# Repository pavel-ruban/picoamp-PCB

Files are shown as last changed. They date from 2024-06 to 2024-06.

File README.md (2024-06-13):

# straddle usb-c connector option (fork changes first 3 images):

pcb|top|bottom|pcb|3d|dev-pcb|dev-3d
--|--|--|--|--|--|--
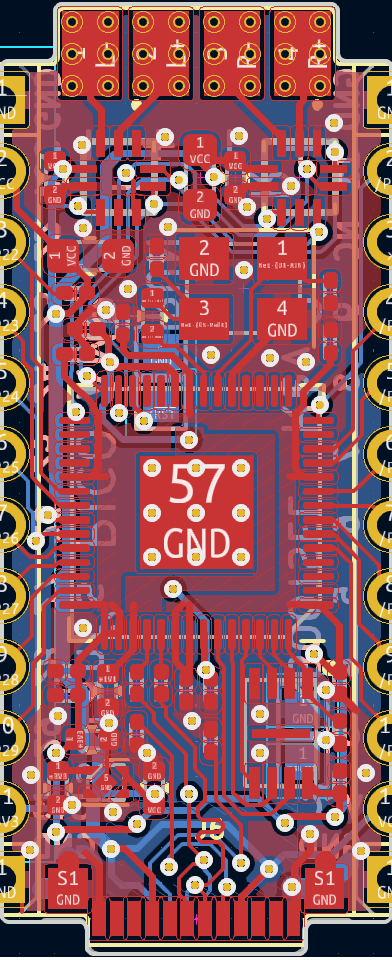
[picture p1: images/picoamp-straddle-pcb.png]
pcb
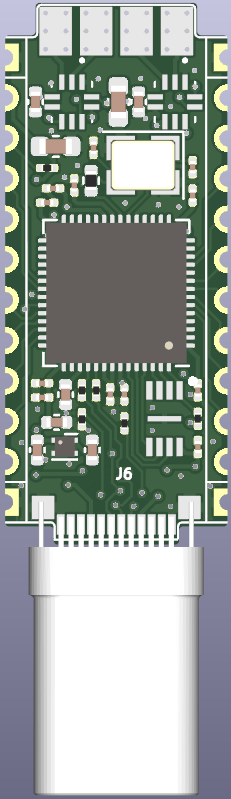
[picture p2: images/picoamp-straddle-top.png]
top
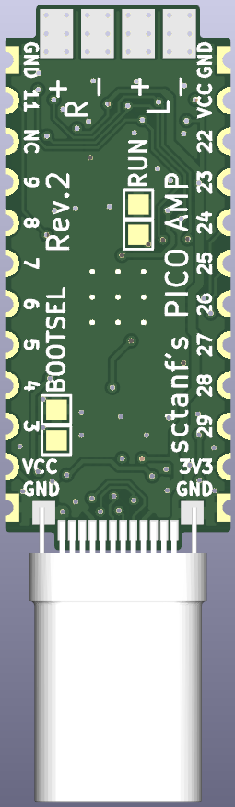
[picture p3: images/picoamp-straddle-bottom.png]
bottom
|||pcb|3d|dev-pcb|dev-3d

* usb c connector https://aliexpress.com/item/1005003274837739.html
* push button soldered on top of the pcb to interact with steamvr dashboard
https://aliexpress.com/item/32622269899.html?sku_id=59394778361

# indexspeakerdacsmol

compact usb-i2s dac using rp2040 and max98360a for powering speakers, like index bmr drivers

* I forgot the silkscreen for usb pins, but they should be clear from below images.
* 0201 components suck to work with.
* intended to use with a usb-c cable, however the CC wire needs 5.1K pull-down to ground which I forgot about

firmware for the device is at https://github.com/sctanf/picoamp

finished board

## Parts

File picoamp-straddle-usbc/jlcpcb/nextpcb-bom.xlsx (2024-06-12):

Manufacturer Part Number* | Qty* | Designator* | FootPrint | JLCPCB Part# | Remarks
CC0402KRX5R6BB104 | 2 | C3,C4 | 0402 | C129131 | ship waste qty with the order pls
0201X104M100CT | 10 | C12,C14,C15,C17,C19,C20,C21,C22,C23,C24 | 0201 | C2443222 | ship waste qty with the order pls
RF03N150F250CT | 2 | C5,C6 | 0201 | C3896518 | ship waste qty with the order pls
CL10A106KP8NNNC | 2 | C1,C2 | 0603 | C19702 | ship waste qty with the order pls
RP2040 | 1 | U1 | LQFN-56(7x7) | C2040 | ship waste qty with the order pls
WR02X102JAL | 1 | R4 | 0201 | C170199 | ship waste qty with the order pls
RM02F5101CT | 3 | R5,R6,R7 | 0201 | C4153144 | ship waste qty with the order pls
RTT0127R0FTH | 10 | R2,R3 | 0201 | C158649 | ship waste qty with the order pls
W25Q16JVUXIQ | 1 | IC3 | USON-8-EP(2x3) | C2843335 | ship waste qty with the order pls
ECS-120-10-33-AGL-TR | 1 | Y1 | SMD3225-4P | C2450497 | ship waste qty with the order pls
ERJ2GEJ102X | 1 | R1 | 0402 | C409846 | ship waste qty with the order pls
MAX98360AEFB+T | 2 | IC1,IC2 | FC2QFN-10(2x2) | C4988888 | ship waste qty with the order pls
MIC5317-3.3YMT-TZ | 1 | U2 | UDFN-4-EP(1x1) | C621348 | ship waste qty with the order pls
GRM155R61C105KA12D | 4 | C7,C8,C16,C18 | 0402 | C77006 | ship waste qty with the order pls
CMS-20103-078SP | 1 | Z3 | speakers | C3311666 | only purchase, no installation, shipped with the order

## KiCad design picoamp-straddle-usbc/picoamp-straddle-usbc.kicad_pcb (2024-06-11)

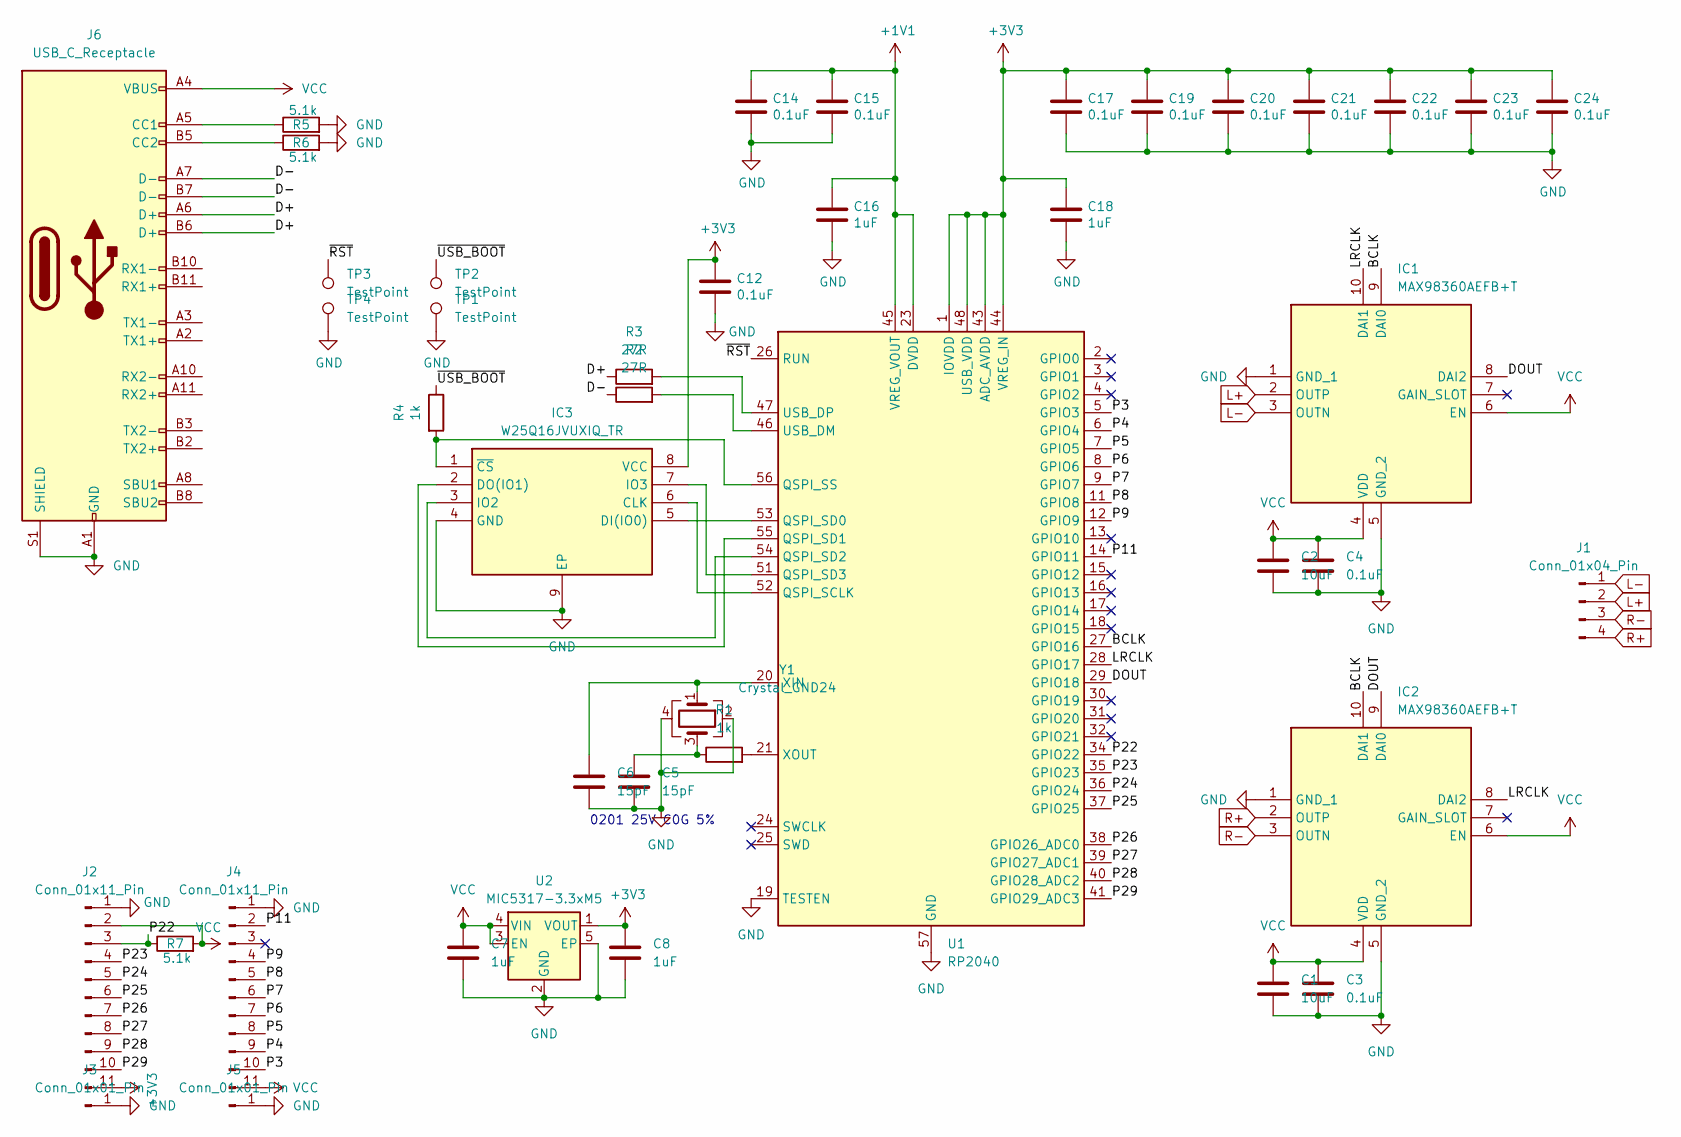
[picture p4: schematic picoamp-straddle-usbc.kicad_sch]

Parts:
C1, C2: 10uF; C_0603_1608Metric; Manufacturer_Part_Number GRM188C81A106MA73D; Mouser Part Number 81-GRM188C81A106MA3D
C3, C4: 0.1uF; C_0402_1005Metric; Manufacturer_Part_Number GRM155R61A104KA01J; Mouser Part Number 81-GRM15R61A104KA01J
C5, C6: 15pF; C_0201_0603Metric; Manufacturer_Part_Number GRM0335C1E150JA01D; Mouser Part Number 81-GRM0335C1E150JA1D
C7, C8, C16, C18: 1uF; C_0402_1005Metric; Manufacturer_Part_Number GRM155C81A105KA12J; Mouser Part Number 81-GRM155C81A105KA2J
C12, C14, C15, C17, C19, C20, C21, C22, C23, C24: 0.1uF; C_0201_0603Metric; Manufacturer_Part_Number GRM033C80J104KE15D; Mouser Part Number 81-GRM33C80J104KE15D
IC1, IC2: MAX98360AEFB+T; MAX98360AEFB; Mouser Part Number 700-MAX98360AEFB+T
IC3: W25Q16JVUXIQ_TR; SON50P300X200X60-9N; Mouser Part Number 454-W25Q16JVUXIQTR
J1: Conn_01x04_Pin; Pin
J2, J4: Conn_01x11_Pin; PinHeader_1x11_P2.00mm_Vertical
J3, J5: Conn_01x01_Pin; PinHeader_1x01_P2.00mm_Vertical
J6: USB_C_Receptacle; USB_C_Plug_Straddle
R1: 1k; R_0402_1005Metric; Manufacturer_Part_Number CRCW04021K00FKED; Mouser Part Number 71-CRCW0402-1.0K-E3
R2, R3: 27R; R_0201_0603Metric; Manufacturer_Part_Number RC0201FR-0727RL; Mouser Part Number 603-RC0201FR-0727RL
R4: 1k; R_0201_0603Metric; Manufacturer_Part_Number CR0201-FW-1001GLF; Mouser Part Number 652-CR0201FW-1001GLF
R5, R6, R7: 5.1k; R_0201_0603Metric; Manufacturer_Part_Number RC0201JR-075K1L; Mouser Part Number 603-RC0201JR-075K1L
TP1, TP2, TP3, TP4: TestPoint; TestPoint_Pad_1.0x1.0mm
U1: RP2040; QFN-56-1EP_7x7mm_P0.4mm_EP3.2x3.2mm; Manufacturer_Part_Number SC0914(7); Mouser Part Number 358-SC09147
U2: MIC5317-3.3xM5; UDFN-4-1EP_1x1mm_P0.65mm_EP0.48x0.48mm; Manufacturer_Part_Number MIC5317-3.3YMT-TR; Mouser Part Number 494-MIC531733YMTTR
Y1: Crystal_GND24; Crystal_SMD_3225-4Pin_3.2x2.5mm; Manufacturer_Part_Number ECS-120-10-33-AGM-TR; Mouser Part Number 520-120-10-33-AGMT

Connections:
+1V1: C14.1, C15.1, C16.1, U1.23 (DVDD), U1.45 (VREG_VOUT), U1.50 (DVDD)
+3V3: C8.1, C12.1, C17.1, C18.1, C19.1, C20.1, C21.1, C22.1, C23.1, C24.1, IC3.8 (VCC), J2.11, U1.1 (IOVDD), U1.10 (IOVDD), U1.22 (IOVDD), U1.33 (IOVDD), U1.42 (IOVDD), U1.43 (ADC_AVDD), U1.44 (VREG_IN), U1.48 (USB_VDD), U1.49 (IOVDD), U2.1 (VOUT)
/BCLK: IC1.9 (DAI0), IC2.10 (DAI1), U1.27 (GPIO16)
/D+: J6.A6 (D+), J6.B6 (D+), R3.1
/D-: J6.A7 (D-), J6.B7 (D-), R2.1
/DOUT: IC1.8 (DAI2), IC2.9 (DAI0), U1.29 (GPIO18)
/LRCLK: IC1.10 (DAI1), IC2.8 (DAI2), U1.28 (GPIO17)
/P3: J4.10, U1.5 (GPIO3)
/P4: J4.9, U1.6 (GPIO4)
/P5: J4.8, U1.7 (GPIO5)
/P6: J4.7, U1.8 (GPIO6)
/P7: J4.6, U1.9 (GPIO7)
/P8: J4.5, U1.11 (GPIO8)
/P9: J4.4, U1.12 (GPIO9)
/P11: J4.2, U1.14 (GPIO11)
/P22: J2.3, R7.1, U1.34 (GPIO22)
/P23: J2.4, U1.35 (GPIO23)
/P24: J2.5, U1.36 (GPIO24)
/P25: J2.6, U1.37 (GPIO25)
/P26: J2.7, U1.38 (GPIO26_ADC0)
/P27: J2.8, U1.39 (GPIO27_ADC1)
/P28: J2.9, U1.40 (GPIO28_ADC2)
/P29: J2.10, U1.41 (GPIO29_ADC3)
/~RST: TP3.1, U1.26 (RUN)
/~USB_BOOT: R4.1, TP2.1
GND: C1.2, C2.2, C3.2, C4.2, C5.2, C6.2, C7.2, C8.2, C12.2, C14.2, C15.2, C16.2, C17.2, C18.2, C19.2, C20.2, C21.2, C22.2, C23.2, C24.2, IC1.1 (GND_1), IC1.5 (GND_2), IC2.1 (GND_1), IC2.5 (GND_2), IC3.4 (GND), IC3.9 (EP), J2.1, J3.1, J4.1, J5.1, J6.A1 (GND), J6.A12 (GND), J6.B1 (GND), J6.B12 (GND), J6.S1 (SHIELD), R5.2, R6.2, TP1.1, TP4.1, U1.19 (TESTEN), U1.57 (GND), U2.2 (GND), U2.5 (EP), Y1.2, Y1.4
L+: IC1.2 (OUTP), J1.2
L-: IC1.3 (OUTN), J1.1
unnamed: C5.1, R1.1, Y1.3
unnamed: IC3.6 (CLK), U1.52 (QSPI_SCLK)
unnamed: IC3.5 (DI(IO0)), U1.53 (QSPI_SD0)
unnamed: IC3.2 (DO(IO1)), U1.55 (QSPI_SD1)
unnamed: IC3.3 (IO2), U1.54 (QSPI_SD2)
unnamed: IC3.7 (IO3), U1.51 (QSPI_SD3)
unnamed: IC3.1 (~CS), R4.2, U1.56 (QSPI_SS)
unnamed: J6.A5 (CC1), R5.1
unnamed: J6.B5 (CC2), R6.1
unnamed: R2.2, U1.46 (USB_DM)
unnamed: R3.2, U1.47 (USB_DP)
unnamed: C6.1, U1.20 (XIN), Y1.1
unnamed: R1.2, U1.21 (XOUT)
R+: IC2.2 (OUTP), J1.4
R-: IC2.3 (OUTN), J1.3
VCC: C1.1, C2.1, C3.1, C4.1, C7.1, IC1.4 (VDD), IC1.6 (EN), IC2.4 (VDD), IC2.6 (EN), J2.2, J4.11, J6.A4 (VBUS), J6.A9 (VBUS), J6.B4 (VBUS), J6.B9 (VBUS), R7.2, U2.3 (EN), U2.4 (VIN)

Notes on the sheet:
0201 25V C0G 5%

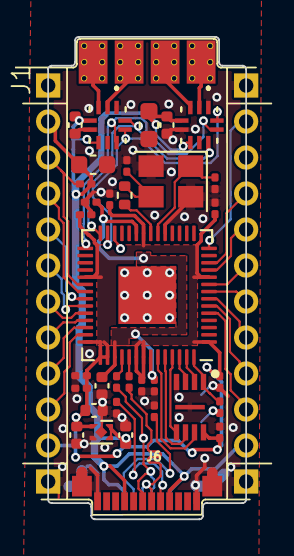
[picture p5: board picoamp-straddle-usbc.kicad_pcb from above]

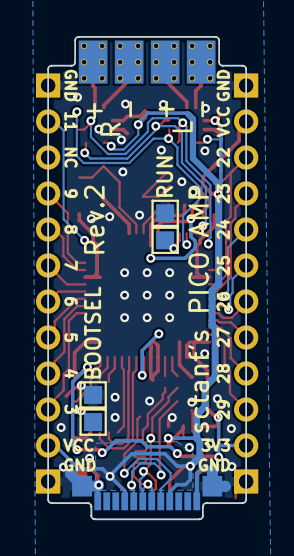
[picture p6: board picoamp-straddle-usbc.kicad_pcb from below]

Board: 2 copper layers, 11.0 x 26.8 mm, 43 parts (5 on the bottom side), 44 nets.

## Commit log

2024-06-11 Added USB C straddle connector & straight pins for speakers, also adjusted PCB to mount a PUSH button on top for gaze dot style interaction.
    [nextpcb-bom.xlsx, picoamp-straddle-usbc.kicad_pcb, picoamp-straddle-usbc.kicad_sch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]
2024-06-12 Fix issue with 0201 components in the BOM file (0603 were chosen by jlcpcb auto tool by default).
    [nextpcb-bom.xlsx]
